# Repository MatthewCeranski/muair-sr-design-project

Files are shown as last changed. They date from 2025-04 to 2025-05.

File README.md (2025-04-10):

# muair-sr-design-project
Construct an air quality sensor and display to actively track your environment! 

## Contributors

This project is maintained by: Matthew Ceranski, George Lambesis, Gaby Chun, David Olatunji, Will Schantz, and Dr. Somesh Roy

We believe in open collaboration! All non-commercial contributions are welcome.

## License

This project is licensed under the [CC BY-NC 4.0](https://creativecommons.org/licenses/by-nc/4.0/) license.  
Feel free to remix, modify, and build upon it for non-commercial purposes — just give credit!

## Sensor Unit
The sensor unit contains the hardware for measuring air quality, including sensors and microcontrollers. It is designed to be lightweight and easy to deploy in various environments.

## Visual Unit
The visual unit is responsible for displaying the data collected by the sensor unit. It connects wirelessly to the sensor unit and shows real-time data on a screen.

## Setup Instructions
To get started, follow the instructions in the [sensor-assembly.md](sensor-unit/sensor-assembly.md) and [visual-assembly.md](visual-unit/visual-assembly.md) for assembling and setting up the units.

## Background
For more information about MUAIR, check out the [background information](background.md)

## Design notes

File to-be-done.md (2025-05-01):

## What Need To Be Taken Care Of

### sensor housing stl
lowkey messed up

does not have any size attributes, fix

I do not have the door file - ask will? not in the teams folders either

I do not have the turn button (for keeping door closed) file - ask will? not in the teams folders either

### visualization housing stl
does not have any size attributes, fix

I do not have the door (right or lefft) file - ask will? not in the teams folders either

I do not have the smokestack file - ask will? not in the teams folders either

### sensor instructions
need to update pictures for each process

need to finish raspberry pi and component install instructions

### visual instructions
need to update pictures for each process

need to finish rasp pi and componenet install instructions

### sensor setup.sh
need to write .sh to create folders, copy python code, setup crontab to keep it easy for user

### visual setup.sh
need to write .sh to create folders, copy python code, setup crontab to keep it easy for user\

## Main To DO
1. read through sensor assembly instructions
      - add images where applicable 
2. read through visualization assembly instructions
      - add images where applicable
      - create circuit diagram 
3. email team
      - need stl files for printing
      - need to access old rpi's (for file setup to make .sh file)
      - send this and ask for updates needed (team review?)
4. create .sh files for setup of raspberry pis
5. send final version to team
6. publish on github
7. return all MUAIR stuff to dr roy lab

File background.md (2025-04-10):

# Design Inspiration

More than 135 million Americans live with polluted air, and disadvantaged communities are most affected by air pollution due to their proximity to freeways and industrial areas. Although there are lots of air quality monitoring tools available, the data outputs may not be well-understood by laypeople, so there is a need to raise environmental awareness by creating easily understandable air quality monitoring tools for disadvantaged communities in the United States. Our senior design group at Marquette University was tasked with designing and prototyping a solution to the rising concern of poor air quality. 

The United States Environmental Protection Agency (EPA) sets the standards for the way AQI is calculated and reported. They created threshold ranges for six different AQI categories and the corresponding colors. We are following the National Ambient Air Quality Standards (NAAQS) for PM. Also, the EPA regulates six pollutants, which the AQI is calculated based on the concentrations of each: ozone, PM2.5, PM10, CO, SO2, NO2. We incorporated this information into our air quality monitoring system appropriately.

# About the Team

This team was comprised of four Marquette University Mechancial Engineers under the supervision of Dr. Somesh Roy. This project turned out to be heavily code based; Matthew and George took on the task of teaching themselves python. Gaby took a strong research role, providing design specifications for the team. David and Will took on the task of designing the housing for both the sensor and visualization.

# Warning

MUAIR is not a tested and calibrated device. While it aims to provide useful information about the local air quality, it cannot be used as a source of data for making decisions regarding health and wellness. This is an educational tool that aims to bring awareness to the environment that we live in. 

MUAIR requires some assembly. Here is a reminder for best practices associated with DIY projects:

•	ALWAYS wear proper personal protective equipment. This includes safety glasses, cut resistant gloves, and respirators. 

•	When working with aerosol materials (sprayable rubber, paint) work in a well-ventilated space. Avoid inhaling vapors.

•	Electrical equipment should never be handled while it is plugged in. Before touching any electrical component, unplug and leave untouched for 1-2 minutes. 

•	If soldering connections, be aware of hot soldering iron. Avoid use of lead solder. Soldier only in well-ventilated areas.

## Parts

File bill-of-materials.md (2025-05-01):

# BILL OF MATERIALS
### Tools for Assembly
| Quantity | Item | Link |
|---|---|---|
| 1 | Monitor with HDMI support |  |
| 1 | Micro HDMI to HDMI Cable (For Raspberry Pi) | [Link](https://www.digikey.com/en/products/detail/raspberry-pi/SC0358/10258775)  |
| 1 | Keyboard and Mouse (USB Connection) |  |
| 1 | 3D Printer |  |
| 1 | 2 kg Spool Filament |  |

### Sensor Unit
| Quantity | Item | Link |
|---|---|---|
| 1 | 4 GB Raspberry-Pi| [Link](https://www.sparkfun.com/raspberry-pi-5-4gb.html) |
| 1 | 15 Watt Power Supply | [Link](https://www.sparkfun.com/raspberry-pi-27w-usb-c-pd-power-supply-white.html) |
| 1 | 128 GB Micro SD Card  | [Link](https://www.amazon.com/Amazon-Basics-microSDXC-Memory-Adapter/dp/B08TJRVWV1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) |
| 2 | SEN55-SDN-T PM Sensor  | [Link](https://www.digikey.com/en/products/detail/sensirion-ag/SEN55-SDN-T/16342756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) |
| 2 | JST Type Connectors  | [Link](https://www.adafruit.com/product/5754) |
| 15 Ft | Solid Core Wire or DuPont Wires | [Link](https://www.digikey.com/en/products/detail/adafruit-industries-llc/1311/6198255) OR [Link](https://www.amazon.com/Elegoo-EL-CP-004-Multicolored-Breadboard-arduino/dp/B01EV70C78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) |
| 1 | 2 x 16 LCD Screen | [Link](https://www.digikey.com/en/products/detail/sunfounder/CN0295D/18668612) |
| 1 | Prototyping Board | [Link](https://www.digikey.com/en/products/detail/dfrobot/FIT0096/7597069) |
| 1 | DFR I2C Multiplexer | [Link](https://www.digikey.com/en/products/detail/dfrobot/DFR0576/9608213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) |
| 1 | Diaphragm Grommet | [Link](https://www.digikey.com/en/products/detail/essentra-components/DG-10187/4104882) |
| 1 | 90 Degree USB-C Adapter | [Link](https://www.amazon.com/Adapter-Degree-Type-C-Support-Transfer/dp/B08TZY4MSR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) |
| 1 | L-Shaped Mountiung Bracket (Optional) | [Link](https://www.homedepot.com/p/Everbilt-4-in-Zinc-Plated-Corner-Brace-2-Pack-15309/202033899) |
| 1 | 2x4 in Acrylic Sheet | [Link](https://www.homedepot.com/p/OPTIX-093-in-x-11-in-x-14-in-Clear-Acrylic-Sheet-1AU0515A/100282591) |
| 1 | Can Sprayable Rubber Coating, Clear | [Link](https://www.homedepot.com/p/FLEX-SEAL-FAMILY-OF-PRODUCTS-14-Ounce-Flex-Seal-Clear-Aerosol-Liquid-Rubber-Sealant-Coating-Spray-Paint-FSCL20/300808900) |

### Visualization Unit
| Quantity | Item | Link |
|---|---|---|
| 1 | 2 GB Raspberry-Pi | [Link](https://www.sparkfun.com/raspberry-pi-5-2gb.html) |
| 1 | 15 Watt Power Supply | [Link](https://www.sparkfun.com/raspberry-pi-27w-usb-c-pd-power-supply-white.html) |
| 1 | 128 GB Micro SD Card | [Link](https://www.amazon.com/Amazon-Basics-microSDXC-Memory-Adapter/dp/B08TJRVWV1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) |
| 3 | Computer Fans | [Link](https://www.digikey.com/en/products/detail/sunon-fans/MF40100V1-1000U-A99/6198732) |
| 15 Ft | Solid Core Wire or DuPont Wires | [Link](https://www.digikey.com/en/products/detail/adafruit-industries-llc/1311/6198255) OR [Link](https://www.amazon.com/Elegoo-EL-CP-004-Multicolored-Breadboard-arduino/dp/B01EV70C78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) |
| 1 | 5" Touch Screen | [Link](https://www.digikey.com/en/products/detail/dfrobot/DFR0550/9608214) |
| 1 | Flexible Cable for Screen  | [Link](https://www.adafruit.com/product/4933) |
| 1 | Prototyping Board | [Link](https://www.digikey.com/en/products/detail/dfrobot/FIT0096/7597069) |
| 3 | 2N2222 Transistors | [Link](https://www.digikey.com/en/products/detail/central-semiconductor-corp/PN2222A-PBFREE/4806937) |
| 1 | Diaphragm Grommet | [Link](https://www.digikey.com/en/products/detail/essentra-components/DG-10187/4104882) |
| 1 | 90 Degree USB-C Adapter | [Link](https://www.amazon.com/Adapter-Degree-Type-C-Support-Transfer/dp/B08TZY4MSR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) |
| 3 | 330 Ohm Resistors | [Link](https://www.digikey.com/en/products/detail/stackpole-electronics-inc/CF14JT330R/1741399) |
| 9 | Plastic Streamers | Make From Plastic Bag |
| 1 | Speaker | [Link](https://www.amazon.com/dp/B07NWFJQJ6?psc=1&ref=ppx_yo2ov_dt_b_product_details) |
| 3 | 2oz Bottles Paint (Optional) |  |

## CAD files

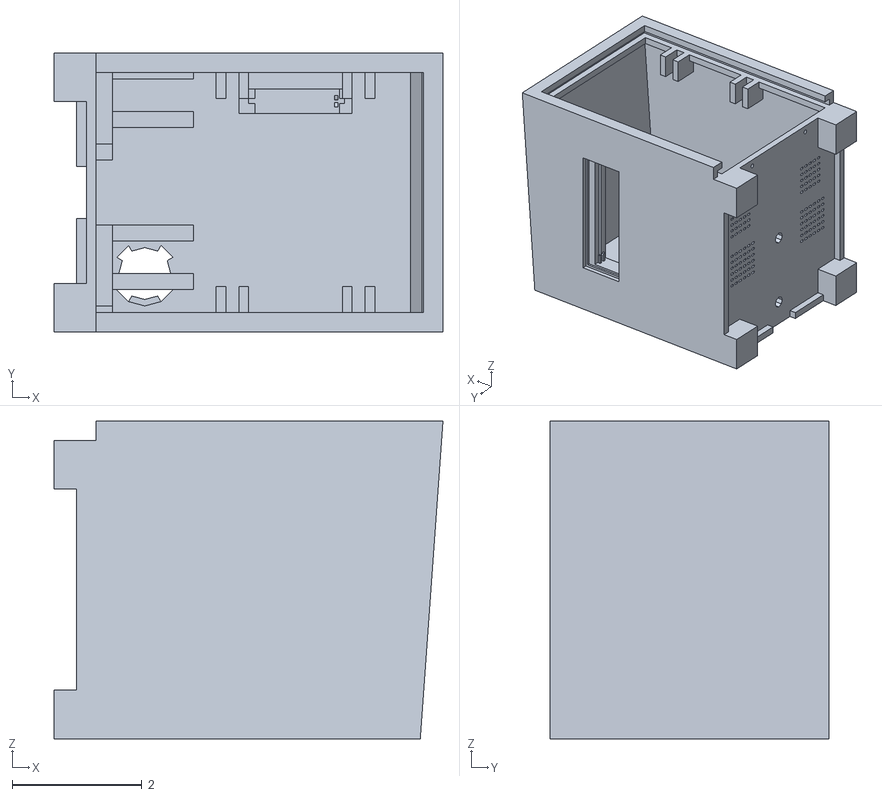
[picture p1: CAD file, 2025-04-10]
sensor-unit/stl/sensor-housing.stl
6.00 x 4.30 x 4.90

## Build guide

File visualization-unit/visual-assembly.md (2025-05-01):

# Visual Unit: Assembly Instructions

## 1. 3D Print the Visualization Housing

Download the STL files and 3D models [here](muair-sr-design-project/visualization-unit/stl).

These parts are not designed to be structural or waterproof on their own. Therefore, any common filament material can be used. The MUAIR team recommends PETG due to its UV resistance and relatively low cost.

If you are new to 3D printing, search for a tutorial based on your specific printer and slicing software. The MUAIR team used Bambu Studio with the preset profile for Bambu Labs PETG Basic.

- Slice and print these models at any point in your build process.
- Because the parts are not structural, you can experiment with slicing parameters to suit your needs.

### Visualization Housing Modification

There is a known clearance issue with the SD card slot on the Raspberry Pi. To resolve this, use a Dremel or other rotary tool to hollow out a **0.5 inch by 0.5 inch** square that is at least **0.15 inches deep** in the corresponding wall of the housing.

Refer to the reference image below for proper placement and dimensions.

*(Insert or link to reference image here)*

---

## 2. Attach Smokestacks to the Visualization Housing

The visualization housing includes decorative smokestacks that need to be attached to the top of the unit.

To secure the smokestacks:

1. Mix a two-part clear epoxy on a sheet of cardboard.
2. Apply small dabs of the mixture to the ends of the smokestacks using toothpicks or Q-Tips.
3. Carefully insert the smokestacks into position, centered around the pre-cut holes on the top of the assembly.

Tip: Wear latex gloves to avoid getting epoxy on your hands. This also makes it easier to wipe off any excess.

Allow the epoxy to cure according to the manufacturer's instructions.

---

## 3. Paint the Visualization Housing (Optional)

Painting is optional but recommended for a more engaging visual experience.

The MUAIR team painted the visualization unit to reflect a realistic factory aesthetic. The more visually compelling the unit is, the more likely it is to spark curiosity and prompt reflection about air quality.

Feel free to be creative—make the visualization stand out and invite interpretation.

---

## 4. Set Up the Visualization Raspberry Pi

Using Raspberry Pi Imager, follow the instructions [here](https://www.raspberrypi.com/documentation/computers/getting-started.html#installing-the-operating-system) to install an operating system and get your raspberry pi up and running. We recommend installing the latest version of Raspberry Pi OS. 

Following setup, you will need to clone this repository to the raspberry pi. In the terminal, copy this code: 
```
git clone https://github.com/your-username/your-repository.git
cd your-repository
```

This will create a copy of the most up to date version of this project. Finally, it is time to set up the raspberry pi to run the MUAIR project automatically. A setup script was created that will download the latest version of python, install the necessary libraries, organize relevant folders, and automate the program. Copy this code into the terminal:
```
bash visual_setup.sh
```

---

## 5. Assemble the Visualization Circuit

Follow the wire diagram provided below. These connections can be soldered for a more permanent unit, or if flexibility is desired these connections can be made on a breadboard. At this point, test the unit to ensure all connections were made correctly. 

---

## 6. Install the Visualization Circuit

Install the assembled components into the visualization housing. The screen is secured with two screws at the bottom of the rear cutout. The fans are tucked into mounts below each smokestack opening. The raspberry pi is set in place on the standouts provided. Attach streamers to the protrusions in each smokestack to give the effect of smoke while the fans are turned on.

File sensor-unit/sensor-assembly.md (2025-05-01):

# Sensor Unit: Assembly Instructions

## 1. 3D Print the Sensor Housing

**Download STL Files**: [Click here to access the 3D models and STL files](sensor-unit/stl/sensor_housing.stl)

These parts are **not designed to be structural or waterproof on their own**, so you can print them with most common filament materials. The MUAIR team recommends **PETG** for its UV resistance and low cost.

If you are new to 3D printing, we suggest searching for tutorials tailored to your specific printer software. The MUAIR team used **Bambu Studio** with the preset profile for **Bambu Labs PETG Basic**.

- You can slice and print the parts at any time during the build process.
- Feel free to modify the model parameters as needed.

>**Note**: In their current state, both the sensor housing and visualization housing **require modification** to fit >internal components.

### Sensor Modification Notice

There is a **known clearance issue** with the sensor module near the screen side of the housing. Specifically, the **inner holding post blocks installation**. Use a Dremel or rotary tool to **remove the post**, leaving approximately **0.25"** remaining to retain stability.

---

## 2. Attach Plexiglass Viewport to Sensor Housing

The sensor housing requires a **2 ¾” x 1” acrylic cover** to be installed over the LCD viewport **before waterproofing**.

### Buying Option:
You can purchase a pre-cut piece of clear acrylic in that size.

### DIY Cutting Option:
1. Use a ruler and fine-tipped Sharpie to mark a rectangle on the plastic cover of a larger acrylic sheet.
2. Cut carefully using a razor blade, acrylic scoring knife, or rotary tool.
3. You can always trim down the piece if it's slightly oversized.
4. **Exercise caution** when cutting.

### Attaching the Cover:
- Mix a **two-part clear epoxy** on cardboard.
- Use toothpicks or Q-tips to apply small dabs of epoxy to the recessed edge of the viewport.
- **Remove the protective plastic film** from the acrylic before applying epoxy.
- Tip: Wear **latex gloves** to avoid mess and for easier cleanup.

 **Cure Time**: Follow the epoxy manufacturer's instructions for drying and curing.

---

## 3. Waterproof the Sensor Housing

To protect internal components, the sensor housing must be waterproofed.

- Use a **sprayable clear rubber coating**.
- **Tape off** the sensor housing as shown in the assembly guide.
- Spray according to the manufacturer’s instructions.

> **DO NOT spray the bottom of the sensor housing.**  
> This area includes vents critical to sensor function — blocking them will reduce accuracy.
> Spray all **other sides** of the housing.

---

## 4. Set Up Sensor Raspberry Pi

Using Raspberry Pi Imager, follow the instructions [here](https://www.raspberrypi.com/documentation/computers/getting-started.html#installing-the-operating-system) to install an operating system and get your raspberry pi up and running. We recommend installing the latest version of Raspberry Pi OS. 

Following setup, you will need to clone this repository to the raspberry pi. In the terminal, copy this code: 
```
git clone https://github.com/your-username/your-repository.git
cd your-repository
```

This will create a copy of the most up to date version of this project. Finally, it is time to set up the raspberry pi to run the MUAIR project automatically. A setup script was created that will download the latest version of python, install the necessary libraries, organize relevant folders, and automate the program. Copy this code into the terminal:
```
bash sensor_setup.sh
```

---

## 5. Assemble the Sensor Circuit

Follow the wire diagram provided below. These connections can be soldered for a more permanent unit, or if flexibility is desired these connections can be made on a breadboard. At this point, test the unit to ensure all connections were made correctly. 

---

## 6. Install the Assembled Sensor Circuit into the Housing

Place each component into the sensor housing. The two air quality sensors will be on the bottom with the fans facing downwards. The LCD screen slides into the slot near the plexiglass viewing window. The breadboard sits on the middle shelf. The raspberry pi fits on the top shelf. Use the wire run cutouts on the back of each shelf to prevent shifting of components.

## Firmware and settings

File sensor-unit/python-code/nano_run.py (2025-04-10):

import sqlite3
import i2clcd
import time
import pandas
import DFRobot_I2C_Multiplexer

#fetch single values from end of database

#connect to database, pull latest numbers
conn=sqlite3.connect('MUAIRtestdatabase', check_same_thread=False)
cursor=conn.cursor()
#fetch temp
cursor.execute("SELECT avg FROM temp ORDER BY rowid DESC LIMIT 1")
tempvalue,=cursor.fetchone()
tempvalue = round(tempvalue,1)

#fetch RH
cursor.execute("SELECT avg FROM temp ORDER BY rowid DESC LIMIT 1")
rhvalue,=cursor.fetchone()
rhvalue = round(rhvalue,1)

#fetch pm1
cursor.execute("SELECT avg FROM pm1 ORDER BY rowid DESC LIMIT 1")
pm1value,=cursor.fetchone()
if pm1value < 100:
    pm1value = round(pm1value,1)
elif pm1value >= 100:
    pm1value = round(pm1value)


#fetch pm2.5
cursor.execute("SELECT avg FROM pm2p5 ORDER BY rowid DESC LIMIT 1")
pm25value,=cursor.fetchone()
if pm25value < 100:
    pm25value = round(pm25value,1)
elif pm25value >= 100:
    pm25value = round(pm25value)

#fetch pm4
cursor.execute("SELECT avg FROM pm4 ORDER BY rowid DESC LIMIT 1")
pm4value,=cursor.fetchone()
if pm4value < 100:
    pm4value = round(pm4value,1)
elif pm4value >= 100:
    pm4value = round(pm4value)

#fetch 10
cursor.execute("SELECT avg FROM pm10 ORDER BY rowid DESC LIMIT 1")
pm10value,=cursor.fetchone()
if pm10value < 100:
    pm10value = round(pm10value,1)
elif pm10value >= 100:
    pm10value = round(pm10value)

#fetch aqi
cursor.execute("SELECT aqi10 FROM aqi10 ORDER BY rowid DESC LIMIT 1")
aqi10value,=cursor.fetchone()
cursor.execute("SELECT aqi25 FROM aqi25 ORDER BY rowid DESC LIMIT 1")
aqi25value,=cursor.fetchone()



if aqi10value > aqi25value:
    aqidisplay = round(aqi10value)
elif aqi25value > aqi10value:
    aqidisplay = round(aqi25value)
elif aqi25value == aqi10value:
    aqidisplay = round(aqi10value)
#have 8 on top
#have 16 on bottom
if aqidisplay <= 50:
    levelaqi = 'Good' #4
    action1 = 'Optimal air!'
    action2 = 'Get Outside Now!'
elif 50 < aqidisplay <= 100:
    levelaqi = 'Moderate' #8
    action1 = 'Moderate Air'
    action2 = 'Monitor AQI!'
elif 100 < aqidisplay <= 150:
    levelaqi = 'Sensitive' #9
    action1 = 'Moderate air'
    action2 = 'Limit Exertion'
elif 150 < aqidisplay <= 200:
    levelaqi = 'Unhealthy' #9
    action1 = 'Poor Air'
    action2 = 'Limit Time Out'
elif 200 < aqidisplay <= 300:
    levelaqi = 'Very Unhealthy' #14
    action1 = '*Bad Air!*'
    action2 = 'Be Careful'
elif aqidisplay > 300:
    levelaqi = 'Dangerous' #9
    action1 = 'Hazardous!'
    action2 = '*Stay Indoors*'


I2CMultiAddr = 0x70     #I2C Multiplexer addr
I2CMulti = DFRobot_I2C_Multiplexer.DFRobot_I2C_Multiplexer(I2CMultiAddr)
I2CMulti.select_port(4)
#export to LCD
# in this loop we can have 'if x is > y, display "x high, stay inside"
lcd = i2clcd.i2clcd(i2c_bus=1, i2c_addr=0x27, lcd_width=16)
while True:
    lcd.init()
    # fill a line by the text
    lcd.clear()
    lcd.move_cursor(0,0)
    lcd.print(f'P1 {pm1value}')
    lcd.move_cursor(1,0)
    lcd.print(f'P4 {pm4value}')
    lcd.move_cursor(0,8)
    lcd.print(f'P25 {pm25value}')
    lcd.move_cursor(1,8)
    lcd.print(f'P10 {pm10value}')
    time.sleep(5)

    lcd.clear()
    lcd.move_cursor(0,0)
    lcd.print(f'RH {rhvalue}')
    lcd.move_cursor(1,0)
    lcd.print(f'Temp {tempvalue}')
    time.sleep(5)

    lcd.clear()
    lcd.move_cursor(0,0)
    lcd.print_line(f'AQI {aqidisplay}', line=0, align='Center')
    lcd.move_cursor(1,0)
    #lcd.print(f'Level is {levelaqi}')
    time.sleep(5)

    lcd.clear()
    lcd.move_cursor(0,0)
    lcd.print_line(f'{action1}', line=0, align='Center')
    lcd.move_cursor(1,0)
    lcd.print_line(f'{action2}', line=1, align='Center')
    time.sleep(5)

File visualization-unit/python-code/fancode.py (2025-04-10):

import time
import math
import sqlite3
from datetime import datetime
import sys
import os
sys.path.append(os.path.dirname(os.path.dirname(os.path.dirname(os.path.realpath(__file__)))))


import RPi.GPIO as GPIO
GPIO.setmode(GPIO.BCM)
import sqlite3
from datetime import datetime
import sqlite3

conn = sqlite3.connect("MUAIRtestdatabase") #connect to database if it exists
conn.row_factory = lambda cursor, row: row[0]
cursor = conn.cursor() #define cursor function

Aqi10 = cursor.execute("SELECT aqi10 FROM aqi10 ORDER BY rowid DESC LIMIT 1").fetchall()
Aqi2p5 = cursor.execute("SELECT aqi25 FROM aqi25 ORDER BY rowid DESC LIMIT 1").fetchall()
#Aqi10=60
#Aqi2p5=1

if Aqi10 > Aqi2p5:
    aqivalue=Aqi10
elif Aqi2p5 > Aqi10:
    aqivalue=Aqi2p5
else:
    aqivalue=Aqi10

print(aqivalue)

RELAIS_1_GPIO=17
GPIO.setup(RELAIS_1_GPIO, GPIO.OUT)
RELAIS_2_GPIO=17,27
GPIO.setup(RELAIS_2_GPIO, GPIO.OUT)
RELAIS_3_GPIO=17,27,22
GPIO.setup(RELAIS_3_GPIO, GPIO.OUT)
GPIO.output(RELAIS_3_GPIO, GPIO.LOW)
time.sleep(3)

while True:
    if 50 < aqivalue <= 150:
        GPIO.output(RELAIS_1_GPIO, GPIO.HIGH) # Turn on the fan
    elif 150 < aqivalue <= 300:
        GPIO.output(RELAIS_2_GPIO, GPIO.HIGH) # Turn on the fan
    elif 300 < aqivalue < 10000:
        GPIO.output(RELAIS_3_GPIO, GPIO.HIGH) # Turn on the fan
    else:
        GPIO.output(RELAIS_3_GPIO, GPIO.LOW)

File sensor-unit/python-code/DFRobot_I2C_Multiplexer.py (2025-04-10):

# -*- coding: utf-8 -*-
'''!
  @DFRobot_I2C_Multiplexer.py
  @brief Raspberry Pi library for I2C cascade module
  @copyright   Copyright (c) 2010 DFRobot Co.Ltd (http://www.dfrobot.com)
  @license     The MIT License (MIT)
  @author      PengKaixing(kaixing.peng@dfrobot.com)
  @maintainer  [qsjhyy](yihuan.huang@dfrobot.com)
  @version  V1.0
  @date  2022-12-06
  @url https://github.com/DFRobot/DFRobot_I2C_Multiplexer
'''
import time
import sys
import smbus

class DFRobot_I2C_Multiplexer:
  '''!
    @brief  I2C cascade module library class
  '''
  def __init__(self,addr):
    self.i2c = smbus.SMBus(1)
    self.addr = addr

  def scan(self,port):
    '''!
      @brief   Scan all I2C devices connected to the I2C cascade module
      @param port  Specify the port for scanning
      @return  Return the I2C address of all devices
    '''
    buf = []
    self.select_port(port)
    for addr in range(0,128):
      if(addr == self.addr):
        continue
      try:
        self.i2c.write_byte(addr,0)
        buf.append(addr)
      except:
        pass
    return buf

  def select_port(self,port):
    '''!
      @brief Enable a specific channel on the I2C multiplexer or disable all channels
      @param port - Select channel, range: 0- 8
      @n 0-7 for enabling the corresponding channel separately, 8 for disabling all channels
      @note When“multiple multiplexer modules” are used on one I2C bus to connect “sensors with same I2C address”, to avoid conflicts,
      @n it is necessary to ensure that “the currently used channel”is the only enabled one among “all channels in all multiplexers”
      @n For instance, when one of the channels in the first multiplexer is enabled, in order to use any channel in the second multiplexer,
      @n please make sure that the channels in the first multiplexer are all disabled.
    '''
    if(port > 8):
      return
    data = (1<<port) & 0xFF
    self.i2c.write_byte(self.addr,data)

  def writeto_mem(self,port,addr,reg,buf):
    '''!
      @brief Write the data into the target I2C device
      @param port    The I2C port that the target device is connected to
      @param addr    I2C address of the target device
      @param reg     Register of the target device to be written
      @param buf     Data of the target device to be written
    '''
    self.select_port(port)
    self.i2c.write_i2c_block_data(addr,reg,buf)

  def readfrom_mem(self,port,addr,reg,nbytes):
    '''!
      @brief  Read the data of the target I2C device
      @param port    The I2C port that the target device is connected to
      @param addr    I2C address of the target device
      @param reg     Register of the target device to be read
      @param nbytes  Data of the target device to be stored
      @return uint8_t read status
    '''
    self.select_port(port)
    return self.i2c.read_i2c_block_data(addr,reg,nbytes)
